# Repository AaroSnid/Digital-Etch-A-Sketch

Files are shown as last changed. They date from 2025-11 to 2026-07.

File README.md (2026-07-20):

# Digital Etch-A-Sketch

The **Digital Etch-A-Sketch** is a portable recreation of the classic Etch-A-Sketch drawing toy, built around an STM32 microcontroller, a 3.5" TFT display, and  rotary encoders for drawing cursor control. This project's main features are the rotary encoder cursor control, realistic screen erase gesture, and selectable drawing thickness.

> **Status:** Major Firmware Version Finalized
> **Hardware Version:** Rev1

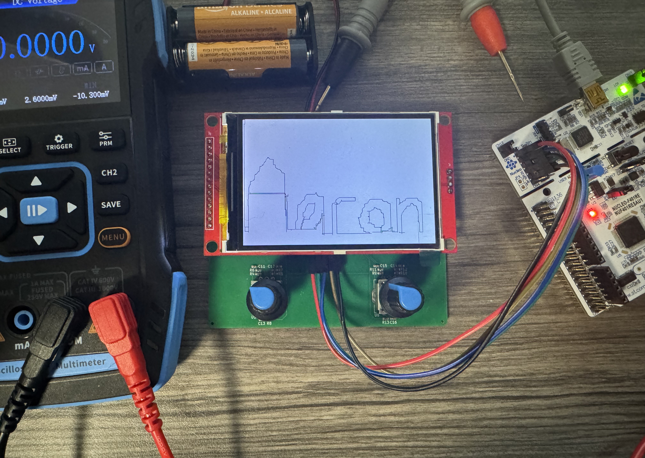
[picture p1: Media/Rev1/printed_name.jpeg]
PCB Rev1 with screen attached


---

## Features

- **Freehand Drawing**
  - Pixel-accurate cursor control
  - Trailless travel / eraser function
  - Selectable drawing thickness and brightness control

- **Physical Controls**
  - Two rotary encoders for X/Y movement
  - Encoder pushbuttons to for system setting selection

- **Shake to Erase**
  - Accelerometer detect motion for realistic screen erase gesture 

- **Portable & Low Power**
  - Powered by 2× AA batteries or by USB-C port

---

## Bill of Materials (Summary)

| Item | Part Number | Qty | Notes |
|---|---|-----|---|
| MCU | STM32L433CCT6 | 1 | Main controller |
| Display | 3.5" ILI9488 SPI | 1 | 3.5" display |
| QSPI Flash | For future expansion | 1 | Reserved for future use |
| 3-axis Accelerometer | LIS3DTHR | 1 | 3-axis velocity sensor |
| Rotary Encoder  | PEC11R-4215F-S0024 | 2 | User input |
| Battery Holder  | Adafruit 4194 | 1 | 2× AA |

---

## Hardware Subsystems

### Power Supply

- **Part:** Adafruit 4194
- **Input:** 2 × AA batteries (2.2–3.2 V)
- **Output:** 3.0 V 
- **Max Load:** ~400 mA
- **Purpose:** Powers the entire system from AA cells

---

### Microcontroller

- **Part:** STM32L433CCT3 / STM32L433CCT6  
- **Clock:** 80 MHz (internal)
- **Memory:**  
  - 256 KB Flash  
  - 64 KB RAM  

**Key Peripherals**

| Function | Peripheral | Notes |
|---|---|---|
| Display | SPI3 | Half-duplex, optimized for fast updates |
| Accelerometer | SPI2, EXTI | Full-duplex |
| Flash memory | Quad-SPI | Memory-mapped reads |
| Rotary Encoders  | TIM1&2, EXTI | QEI mode with interrupts |
| Debug | SWD | DIO, CLK, NRST |

---

### Display

- **Type:** 3.5" TFT Display
- **Controller:** ILI9488
- **Interface:** Dedicated 4-wire SPI
- **Power:** 3.3 V
- **Frame Buffer:** Embedded GRAM
- **Update Modes:** Full and partial refresh
The screen is mounted to the board using the female pin headers on either side. The touchscreen functionality of the screen is not used, so the touchscreen pins are not conected.

---

### Storage

- **Part:** For future expansion
- **Capacity:** Reserved for future use
- **Interface:** Quad SPI (if added later)
- **Purpose:**
  - Potential animation frame storage
  - Potential configuration data

---

### Motion Sensor

- **Part:** LIS3DTHR
- **Interface:** SPI
- **Capabilities:** 3-axis accelerometer
- **Usage:**
  - Detect shake gesture for screen erase
  - Uses interrupts for main motion detection
  - SPI available as fallback

---

### Rotary Encoders

- **Quantity:** 2
- **Part:** PEC11R-4215F-S0024
- **Purpose:**
  - X-axis and Y-axis cursor movement
  - UI interaction via push buttons

**Connections**
- A/B channels → Timer QEI inputs
- Buttons → EXTI interrupts
- Hardware Pull-ups (open-drain behavior)

---

## Firmware Architecture

### Overview

The firmware runs inside of a state machine, easily allowing for the same user inputs to be used for different purposes.
The main loop runs (per iteration) a check for the screen erase, handles state change, and then enters the state machine section for currently selected action.
An external driver is used for the ILI9488 display, all other firmware is made by me.

---

## Debug & Firmware Update

- **Interface:** SWD
- **Exposed Pins:**  
  - SWDIO  
  - SWCLK  
  - NRST  
  - VCC + GND

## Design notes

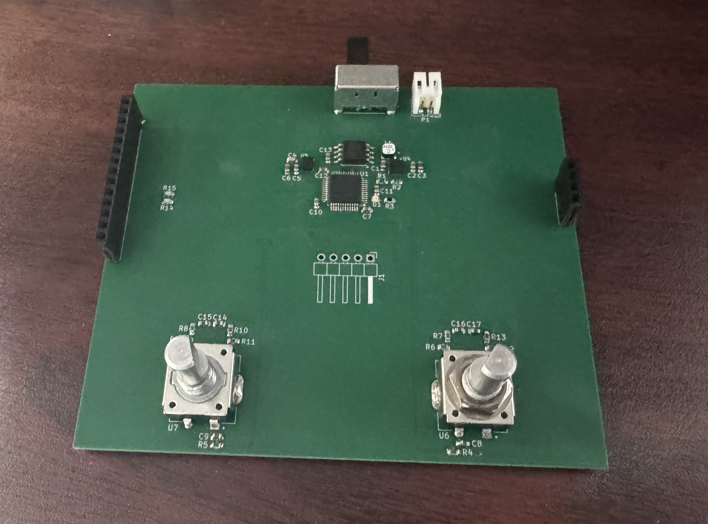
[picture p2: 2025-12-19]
Media/pcb_rev0.JPG

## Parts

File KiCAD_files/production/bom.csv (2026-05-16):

Designator | Footprint | Quantity | Value | LCSC Part #
C1, C10, C2, C20, C4, C5, C6 | 0603 | 7 | 0.1uF
C11, C12, C14, C15 | 0603 | 4 | 0.22uF
C13, C16 | 0603 | 2 | 0.47uF
C17, C18, C8 | 0603 | 3 | 1uF
C19, C3 | 0603 | 2 | 10uF
C7 | 0603 | 1 | 10nF
C9 | 0603 | 1 | 4.7uF
J1 | PinHeader_1x05_P2.54mm_Vertical | 1 | Debug Connector
J2 | PinSocket_1x14_P2.54mm_Vertical | 1 | Display / Mounting Socket
J3 | PinSocket_1x04_P2.54mm_Vertical | 1 | Display Mounting Socket
J4 | 2171790001_MOL | 1 | Molex 2171790001
P1 | JST_PH_B2B-PH-K_1x02_P2.00mm_Vertical | 1 | 282837-2
R1, R10, R11, R12, R13, R2, R3, R4, R5, R6, R7, R8, R9 | 0603 | 13 | 10K
R14, R15 | 0603 | 2 | 5.1kΩ
S1 | OS102011MA1QN1_CNK | 1 | OS102011MA1QN1
U1 | LQFP-48_7x7mm_P0.5mm | 1 | STM32L433CCTx
U2 | SOIC-8_5P28X5P28_WIN | 1 | W25Q64JV
U3 | LGA-16_3x3x1mm_STM | 1 | LIS3DHTR
U4 | SOT-23 | 1 | MCP1700x-300xxTT
U5, U6 | XDCR_PEC11R-4215F-S0024 | 2 | PEC11R_4215F_S0024

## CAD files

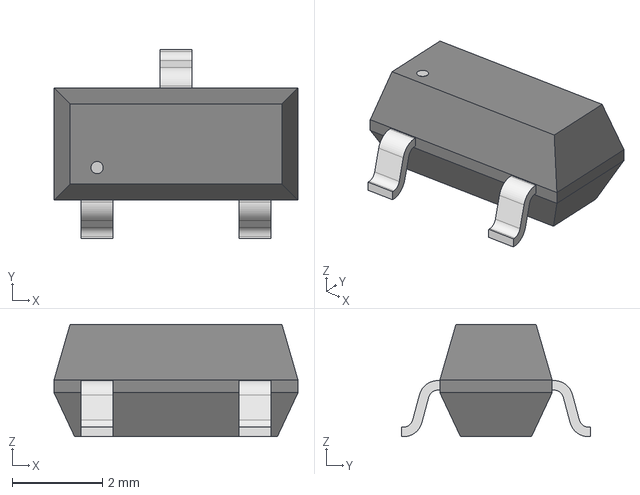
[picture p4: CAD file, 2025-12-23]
KiCAD_files/CJS_1200TB/CJS-1200B_NDC.step
5.41 x 4.19 x 2.49 mm

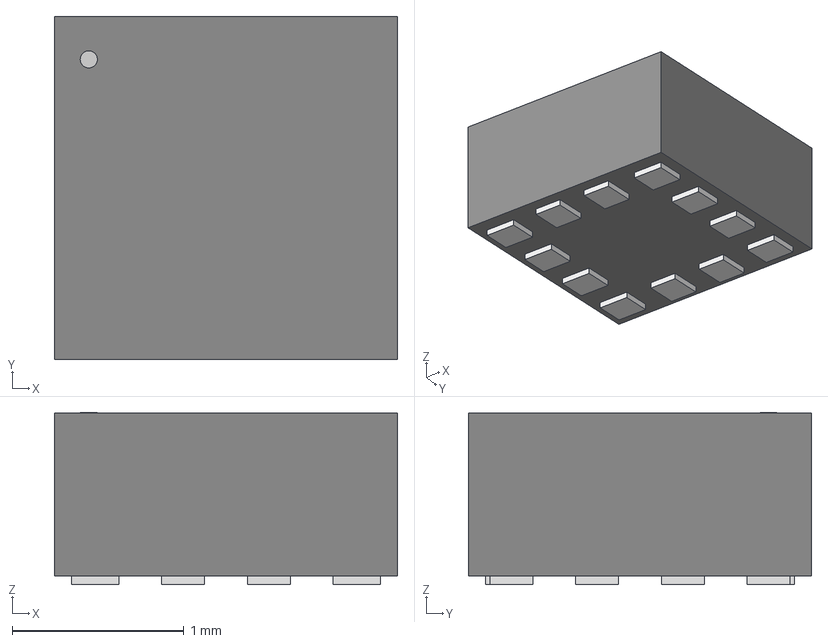
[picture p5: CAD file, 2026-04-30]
KiCAD_files/LIS2DH12TR/LGA-12_STM.step
2.00 x 2.00 x 1.00 mm

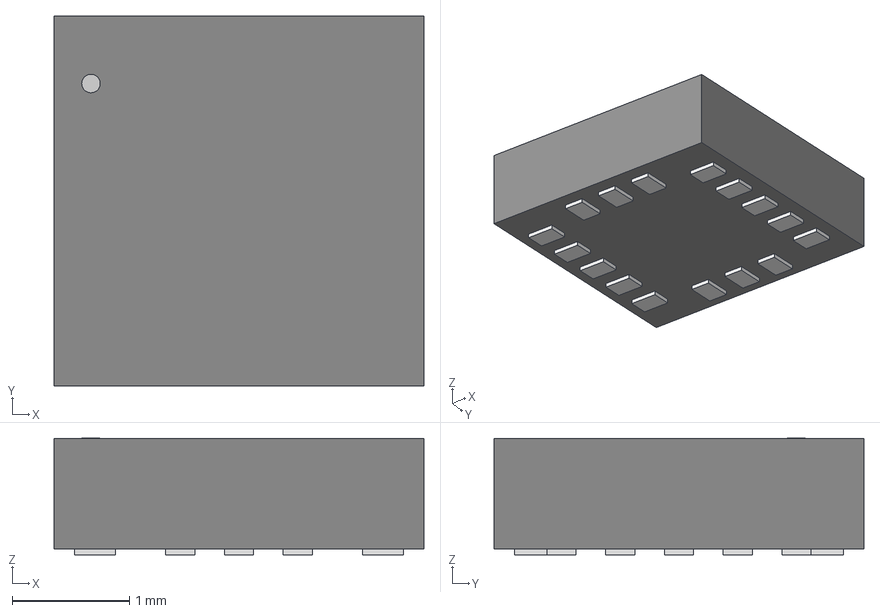
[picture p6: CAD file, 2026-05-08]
KiCAD_files/LIS3DHTR/LGA-16_3x3x1mm_STM.step
3.15 x 3.15 x 0.993 mm

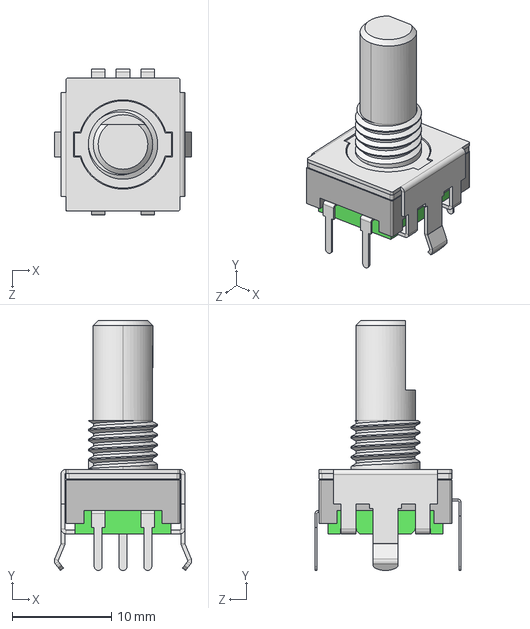
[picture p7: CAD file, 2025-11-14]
KiCAD_files/PEC11R_4215F_S0024/PEC11R-4215F-S0024.step
13.9 x 25.2 x 14.7 mm

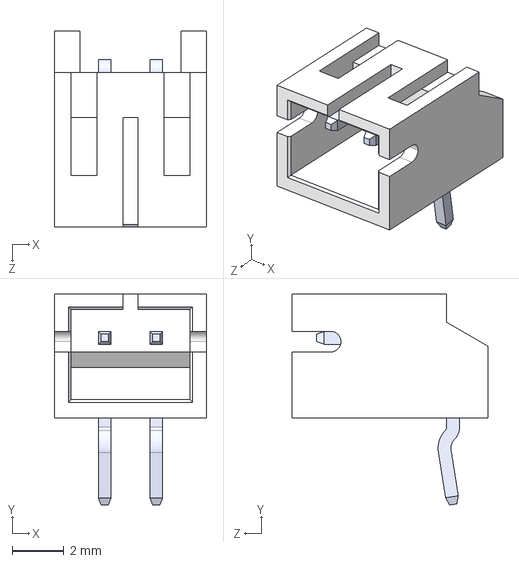
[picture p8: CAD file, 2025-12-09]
KiCAD_files/S2B_PH_K_S/S2B-PH-K-S.STEP
5.90 x 8.18 x 7.60 mm

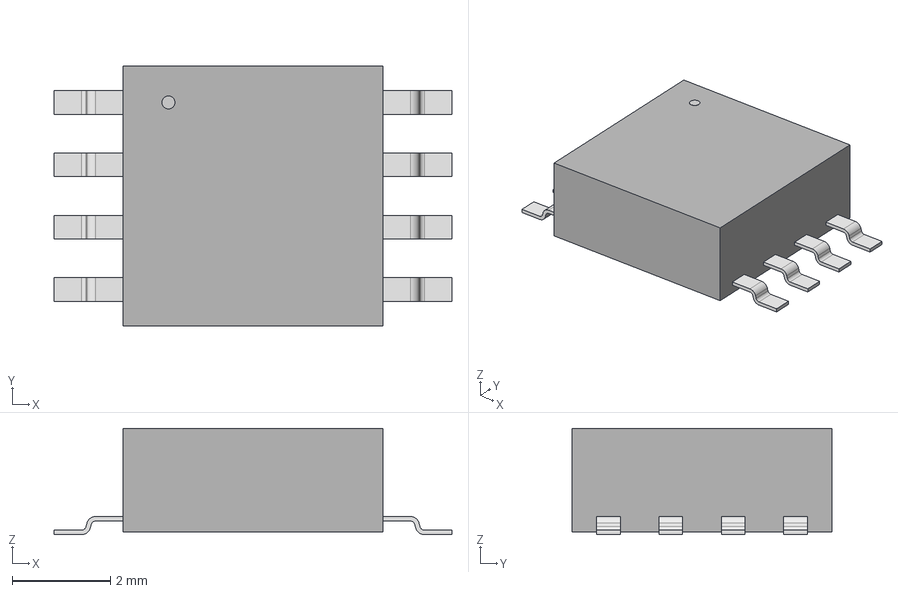
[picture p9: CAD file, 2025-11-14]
KiCAD_files/W25Q64JVSSIQ/SOIC-8_5P28X5P28_WIN.step
8.10 x 5.28 x 2.16 mm

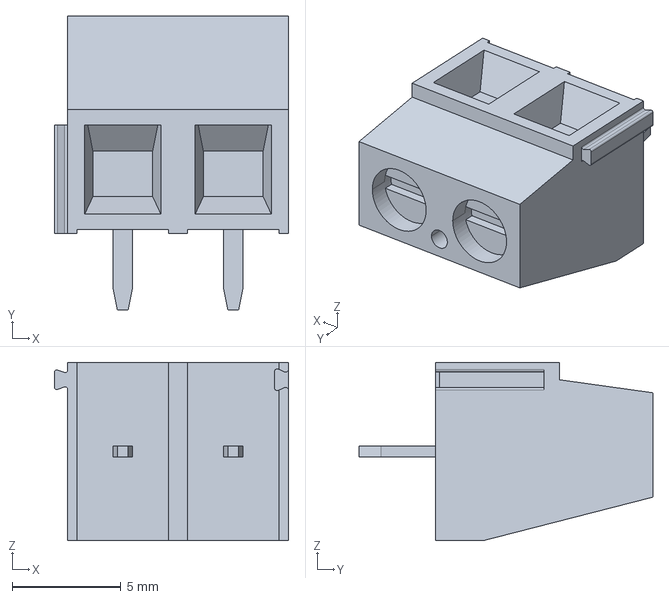
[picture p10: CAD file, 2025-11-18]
KiCAD_files/282837_2/282837-2.step
10.8 x 13.5 x 8.20 mm

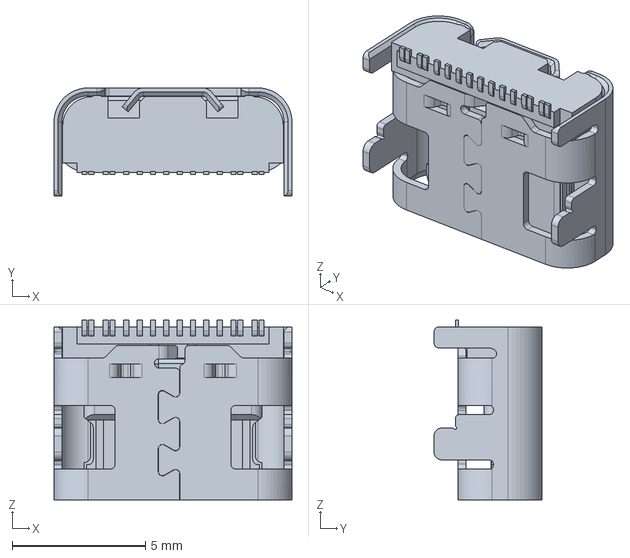
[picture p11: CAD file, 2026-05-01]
KiCAD_files/Molex2171790001/2171790001.stp
8.94 x 4.06 x 6.75 mm

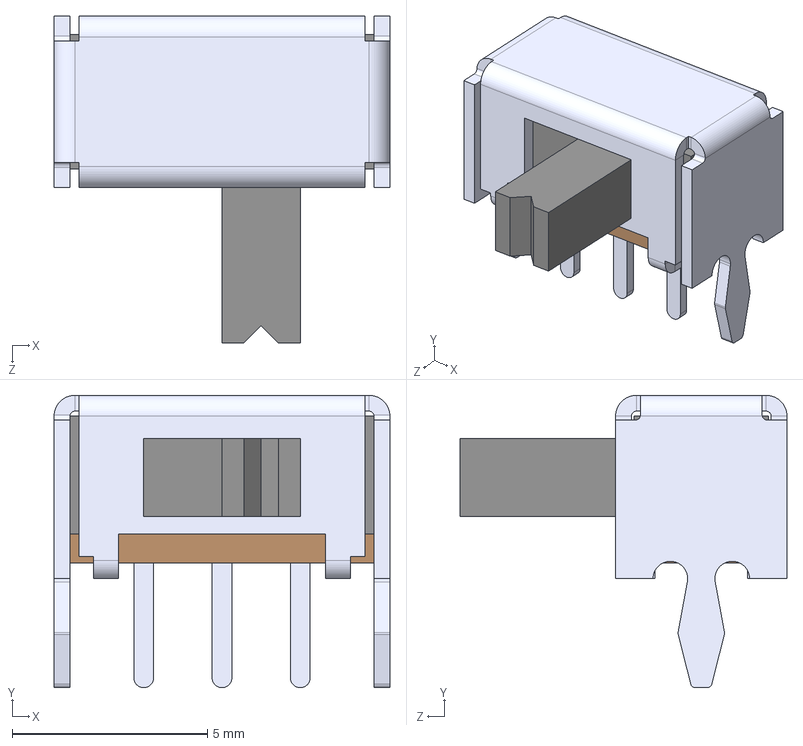
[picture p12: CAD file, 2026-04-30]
KiCAD_files/OS102011MA1QN1/OS102011MA1QN1.STEP
8.61 x 7.49 x 8.38 mm

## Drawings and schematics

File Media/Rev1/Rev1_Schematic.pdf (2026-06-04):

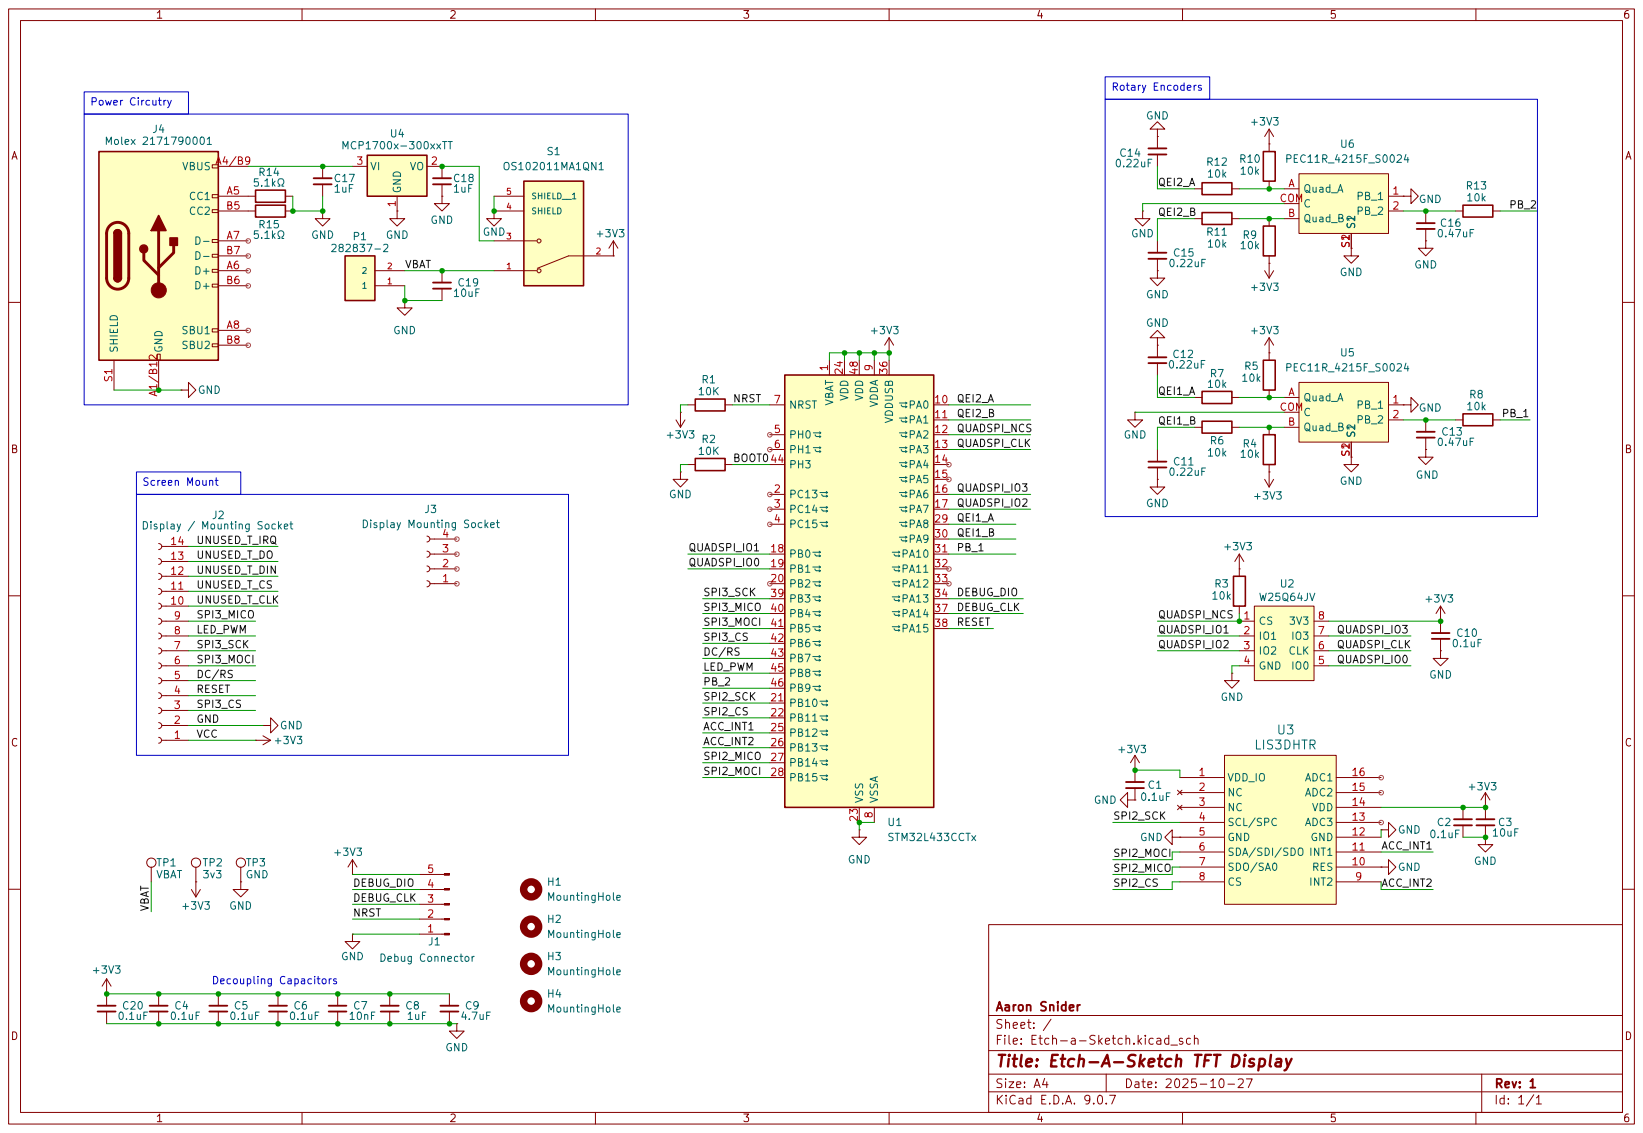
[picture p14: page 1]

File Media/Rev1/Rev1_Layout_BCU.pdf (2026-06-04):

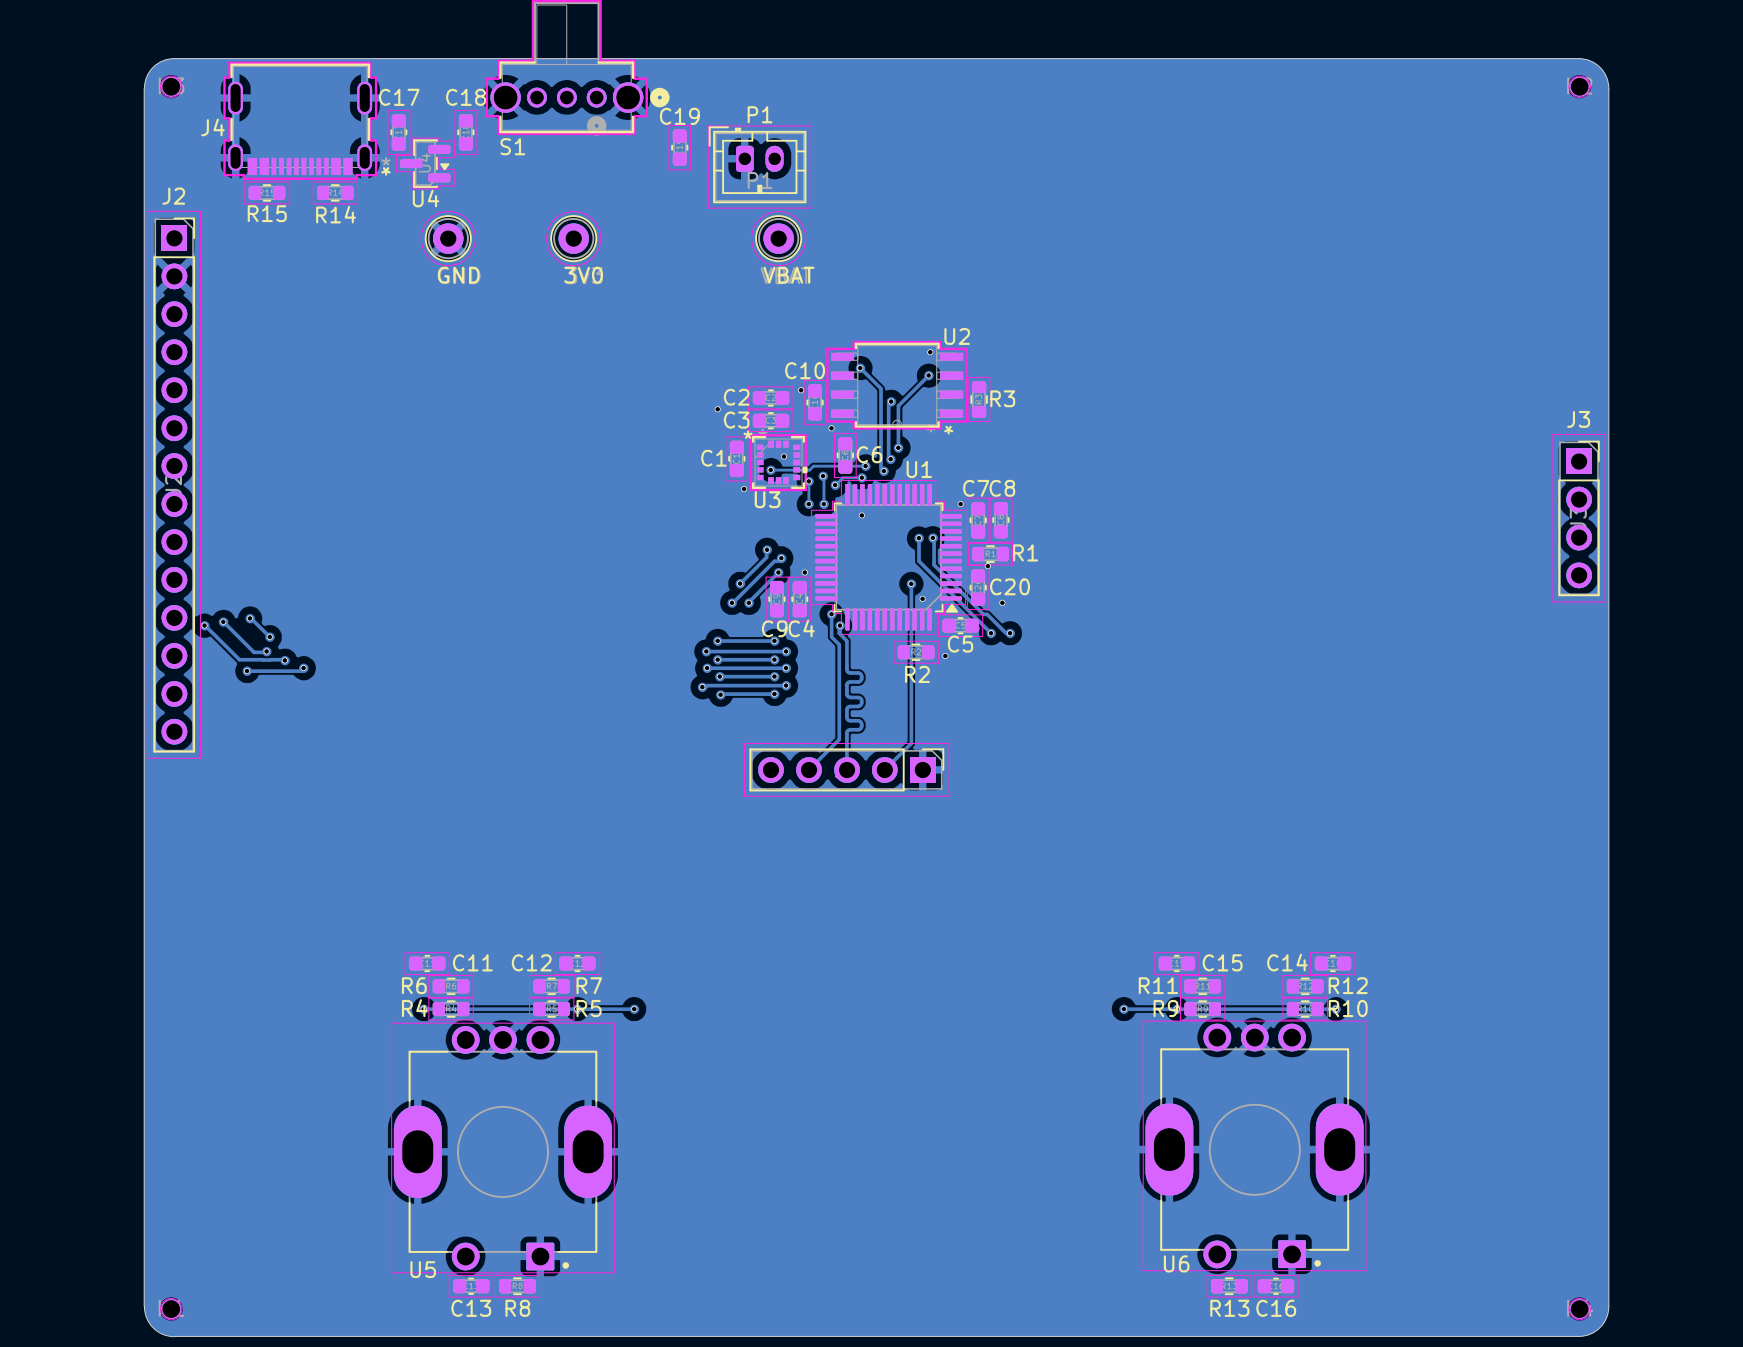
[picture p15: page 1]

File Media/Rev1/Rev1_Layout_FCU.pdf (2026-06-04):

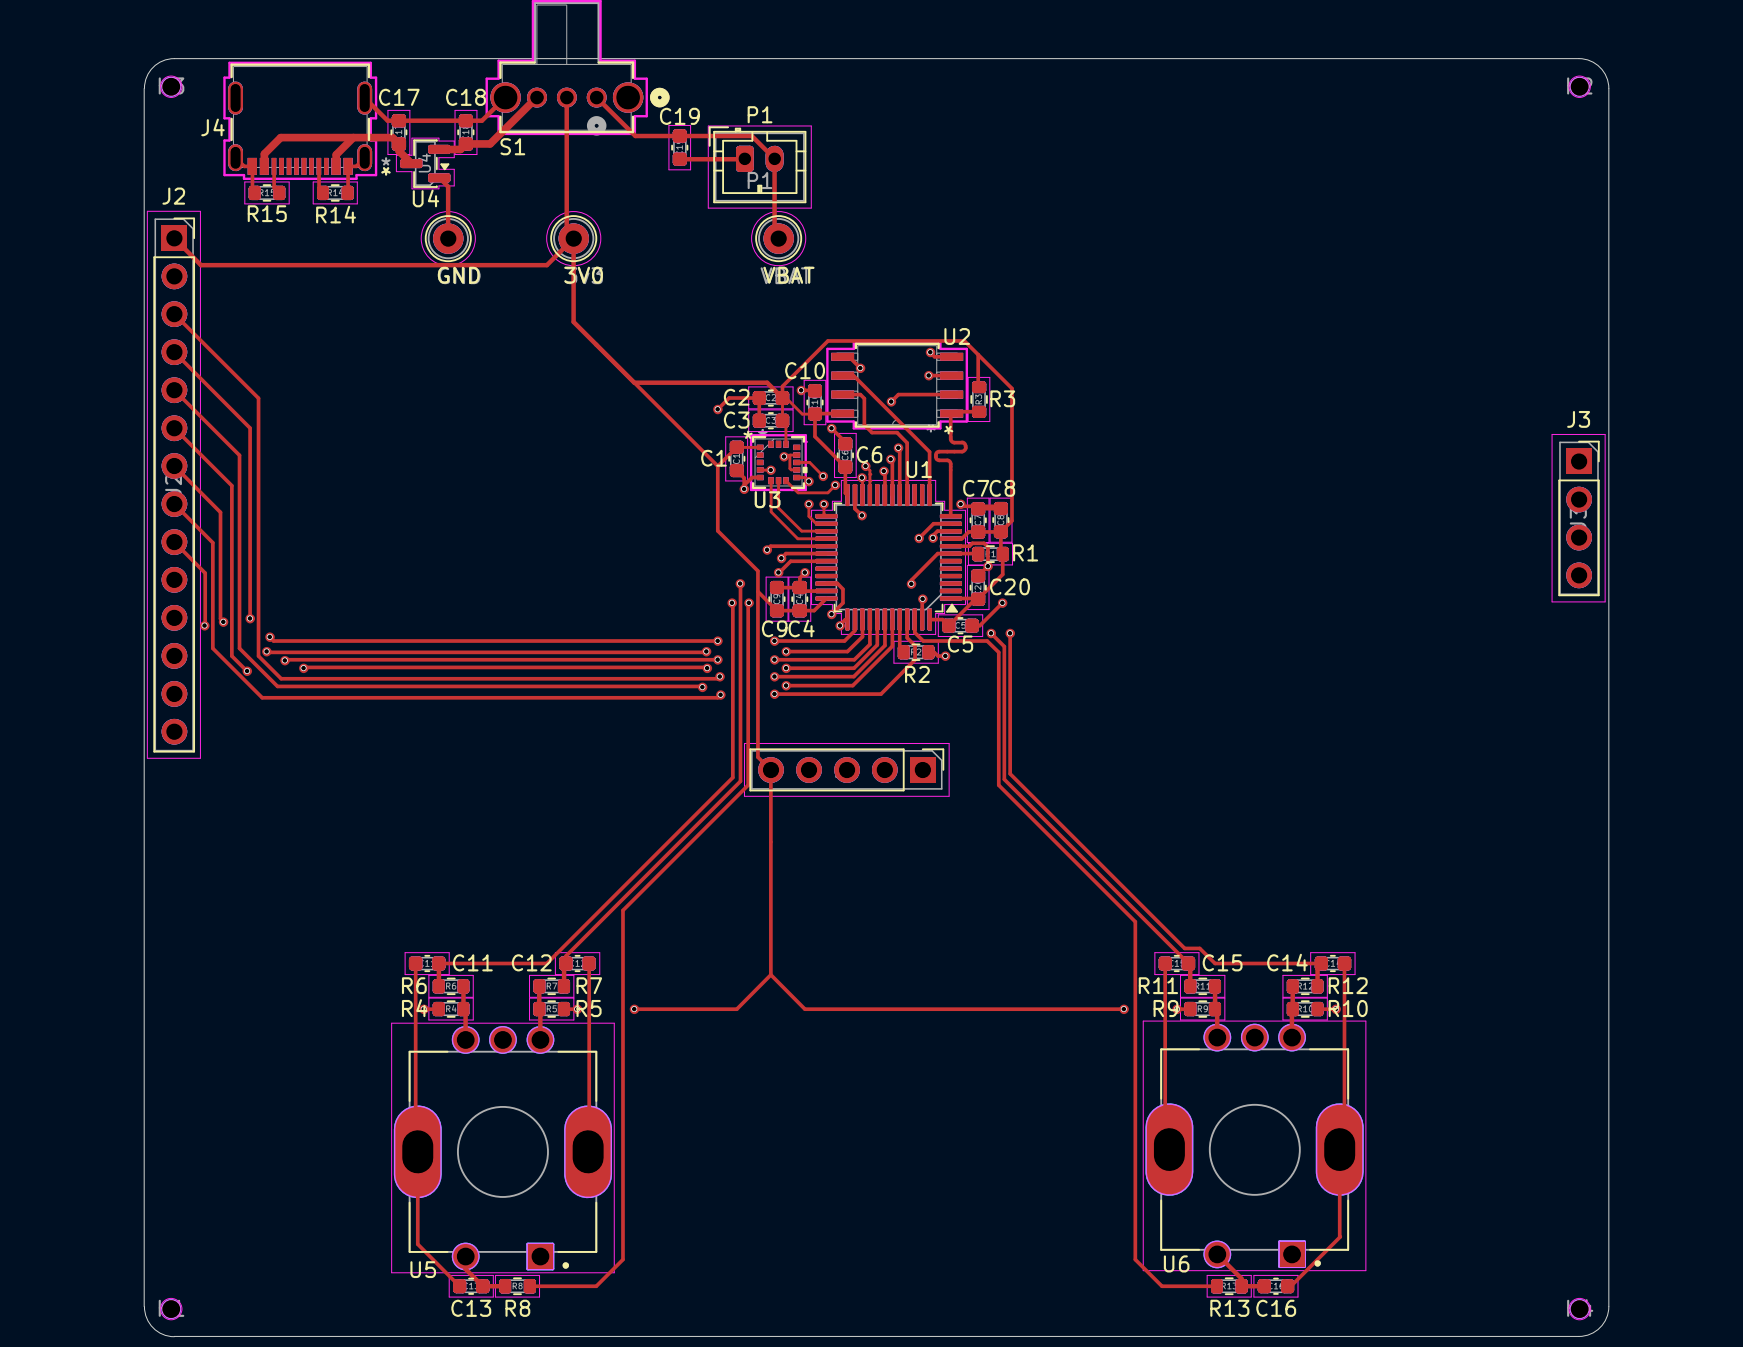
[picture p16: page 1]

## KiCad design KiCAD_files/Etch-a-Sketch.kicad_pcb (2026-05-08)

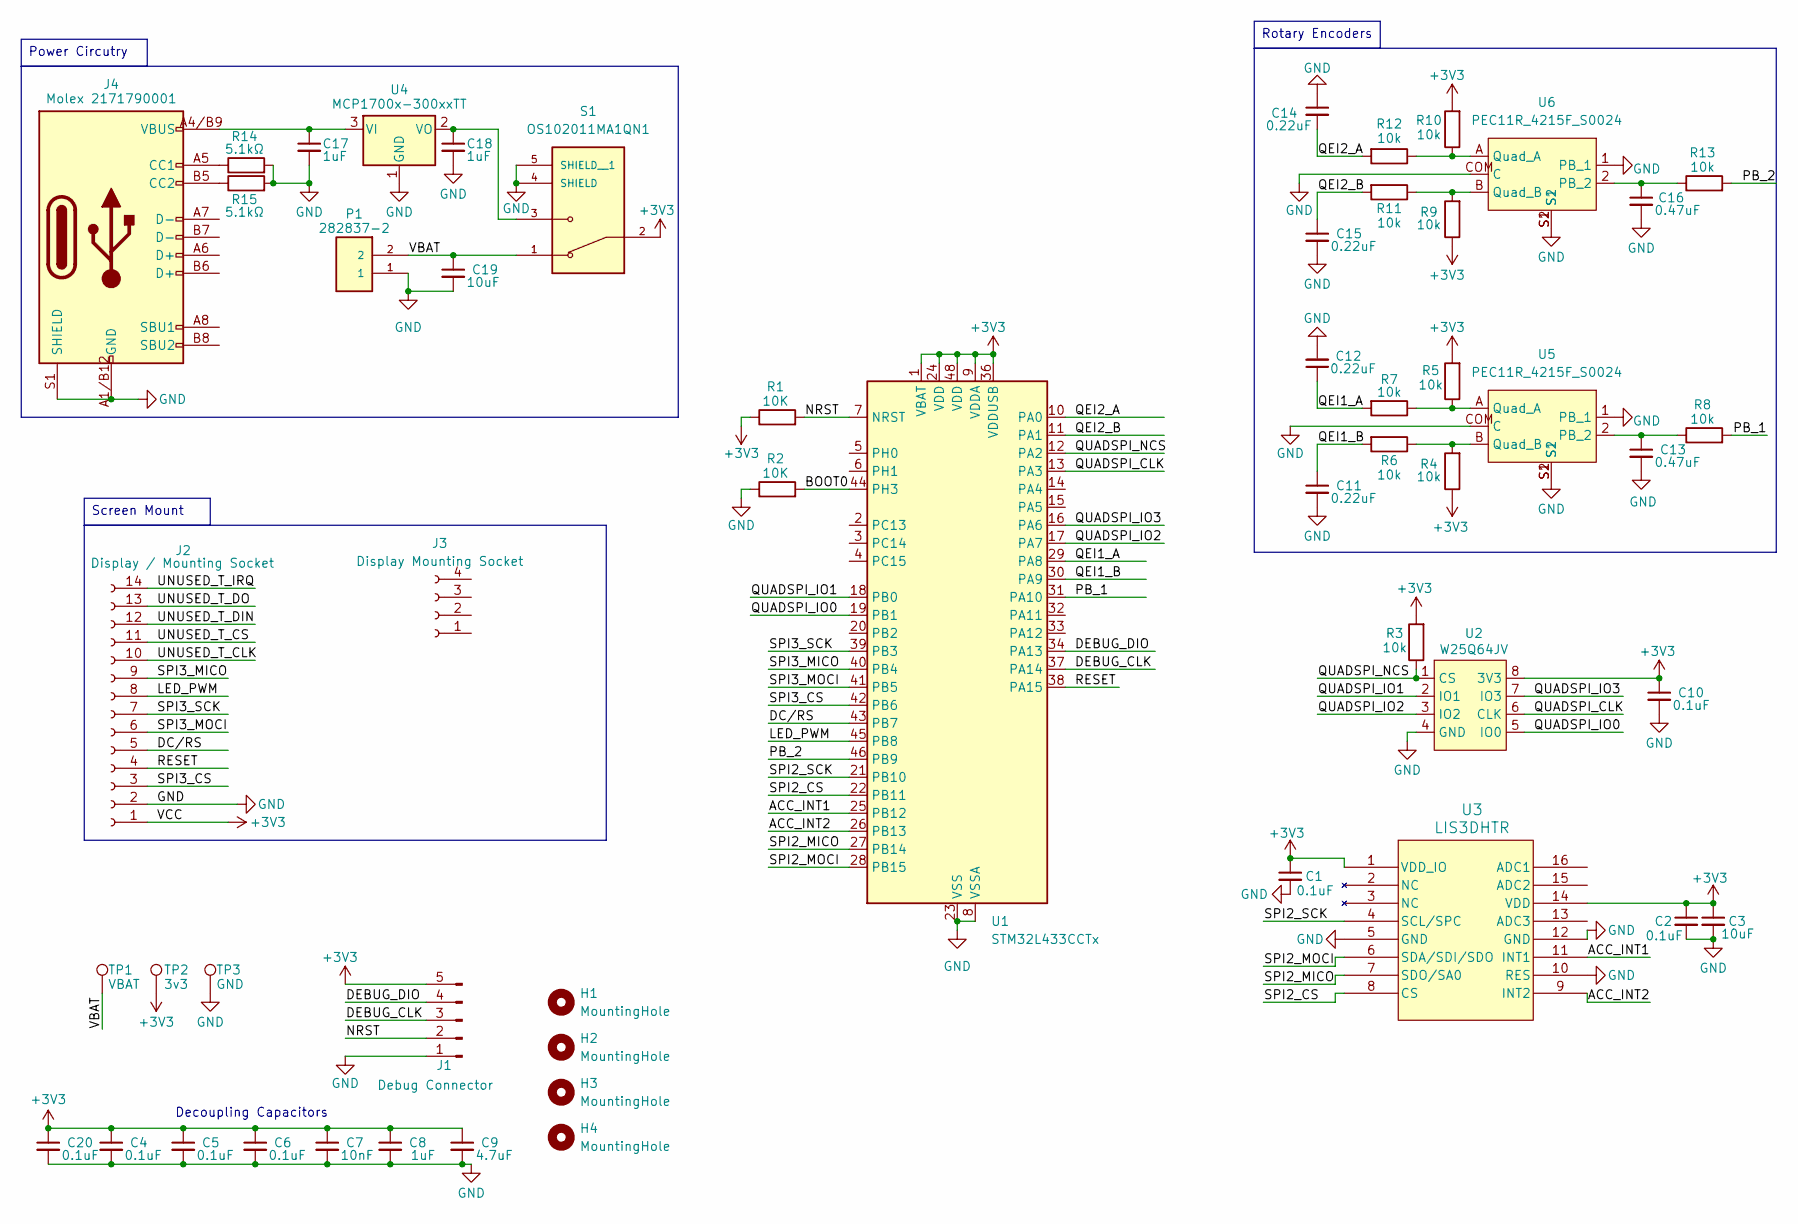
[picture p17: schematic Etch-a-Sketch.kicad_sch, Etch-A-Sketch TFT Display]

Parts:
C1, C2, C4, C5, C6, C10, C20: 0.1uF; C_0603_1608Metric
C3, C19: 10uF; C_0603_1608Metric
C7: 10nF; C_0603_1608Metric
C8, C17, C18: 1uF; C_0603_1608Metric
C9: 4.7uF; C_0603_1608Metric
C11, C12, C14, C15: 0.22uF; C_0603_1608Metric
C13, C16: 0.47uF; C_0603_1608Metric
H1, H2, H3, H4: MountingHole; ToolingHole_1.152mm
J1: Debug Connector; PinHeader_1x05_P2.54mm_Vertical
J2: Display / Mounting Socket; PinSocket_1x14_P2.54mm_Vertical
J3: Display Mounting Socket; PinSocket_1x04_P2.54mm_Vertical
J4: Molex 2171790001; 2171790001_MOL
P1: 282837-2; JST_PH_B2B-PH-K_1x02_P2.00mm_Vertical; PARTREV G3
R1, R2: 10K; R_0603_1608Metric
R3, R4, R5, R6, R7, R8, R9, R10, R11, R12, R13: 10k; R_0603_1608Metric
R14, R15: 5.1kΩ; R_0603_1608Metric
S1: OS102011MA1QN1; OS102011MA1QN1_CNK; PARTREV A
TP1: VBAT; TestPoint_Loop_D1.80mm_Drill1.0mm_Beaded
TP2: 3v3; TestPoint_Loop_D1.80mm_Drill1.0mm_Beaded
TP3: GND; TestPoint_Loop_D1.80mm_Drill1.0mm_Beaded
U1: STM32L433CCTx; LQFP-48_7x7mm_P0.5mm
U2: W25Q64JV; SOIC-8_5P28X5P28_WIN
U3: LIS3DHTR; LGA-16_3x3x1mm_STM
U4: MCP1700x-300xxTT; SOT-23
U5, U6: PEC11R_4215F_S0024; XDCR_PEC11R-4215F-S0024

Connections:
+3V3: C1.1, C2.1, C3.1, C4.1, C5.1, C6.1, C7.1, C8.1, C9.1, C10.1, C20.1, J1.5, J2.1, R1.1, R3.2, R4.1, R5.2, R9.1, R10.2, S1.2, TP2.1, U1.1 (VBAT), U1.9 (VDDA), U1.24 (VDD), U1.36 (VDDUSB), U1.48 (VDD), U2.8 (3V3), U3.1 (VDD_IO), U3.14 (VDD); also elsewhere on the board
/ACC_INT1: U1.25 (PB12), U3.11 (INT1)
/ACC_INT2: U1.26 (PB13), U3.9 (INT2)
/BOOT0: R2.2, U1.44 (PH3)
/DC/RS: J2.5, U1.43 (PB7)
/DEBUG_CLK: J1.3, U1.37 (PA14)
/DEBUG_DIO: J1.4, U1.34 (PA13)
/LED_PWM: J2.8, U1.45 (PB8)
/NRST: J1.2, R1.2, U1.7 (NRST)
/PB_1: R8.2, U1.31 (PA10)
/PB_2: R13.2, U1.46 (PB9)
/QEI1_A: C12.1, R7.2, U1.29 (PA8)
/QEI1_B: C11.1, R6.2, U1.30 (PA9)
/QEI2_A: C14.2, R12.2, U1.10 (PA0)
/QEI2_B: C15.1, R11.2, U1.11 (PA1)
/QUADSPI_CLK: U1.13 (PA3), U2.6 (CLK)
/QUADSPI_IO0: U1.19 (PB1), U2.5 (IO0)
/QUADSPI_IO1: U1.18 (PB0), U2.2 (IO1)
/QUADSPI_IO2: U1.17 (PA7), U2.3 (IO2)
/QUADSPI_IO3: U1.16 (PA6), U2.7 (IO3)
/QUADSPI_NCS: R3.1, U1.12 (PA2), U2.1 (CS)
/RESET: J2.4, U1.38 (PA15)
/SPI2_CS: U1.22 (PB11), U3.8 (CS)
/SPI2_MICO: U1.27 (PB14), U3.7 (SDO/SA0)
/SPI2_MOCI: U1.28 (PB15), U3.6 (SDA/SDI/SDO)
/SPI2_SCK: U1.21 (PB10), U3.4 (SCL/SPC)
/SPI3_CS: J2.3, U1.42 (PB6)
/SPI3_MICO: J2.9, U1.40 (PB4)
/SPI3_MOCI: J2.6, U1.41 (PB5)
/SPI3_SCK: J2.7, U1.39 (PB3)
/UNUSED_T_CLK: J2.10
/UNUSED_T_CS: J2.11
/UNUSED_T_DIN: J2.12
/UNUSED_T_DO: J2.13
/UNUSED_T_IRQ: J2.14
/VBAT: C19.1, P1.2, S1.1, TP1.1; also elsewhere on the board
GND: C1.2, C2.2, C3.2, C4.2, C5.2, C6.2, C7.2, C8.2, C9.2, C10.2, C11.2, C12.2, C13.2, C14.1, C15.2, C16.2, C17.2, C18.2, C19.2, C20.2, J1.1, J2.2, J4.A1/B12 (GND), J4.B1/A12 (GND), J4.S1 (SHIELD), P1.1, R2.1, R14.2, R15.2, S1.4 (SHIELD), S1.5 (SHIELD__1), TP3.1, U1.8 (VSSA), U1.23 (VSS), U1.35 (VSS), U1.47 (VSS), U2.4 (GND), U3.5 (GND), U3.10 (RES), U3.12 (GND), U4.1 (GND), U5.1 (PB_1), U5.COM (C), U5.S1, U5.S2, U6.1 (PB_1), U6.COM (C), U6.S1, U6.S2; also elsewhere on the board
unnamed: J4.A5 (CC1), R14.1
unnamed: J4.B5 (CC2), R15.1
unnamed: C17.1, J4.A4/B9 (VBUS), J4.B4/A9 (VBUS), U4.3 (VI)
unnamed: C18.1, S1.3, U4.2 (VO)
unnamed: C13.1, R8.1, U5.2 (PB_2)
unnamed: R5.1, R7.1, U5.A (Quad_A)
unnamed: R4.2, R6.1, U5.B (Quad_B)
unnamed: C16.1, R13.1, U6.2 (PB_2)
unnamed: R10.1, R12.1, U6.A (Quad_A)
unnamed: R9.2, R11.1, U6.B (Quad_B)

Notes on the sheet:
Decoupling Capacitors
Screen Mount
Rotary Encoders
Power Circutry

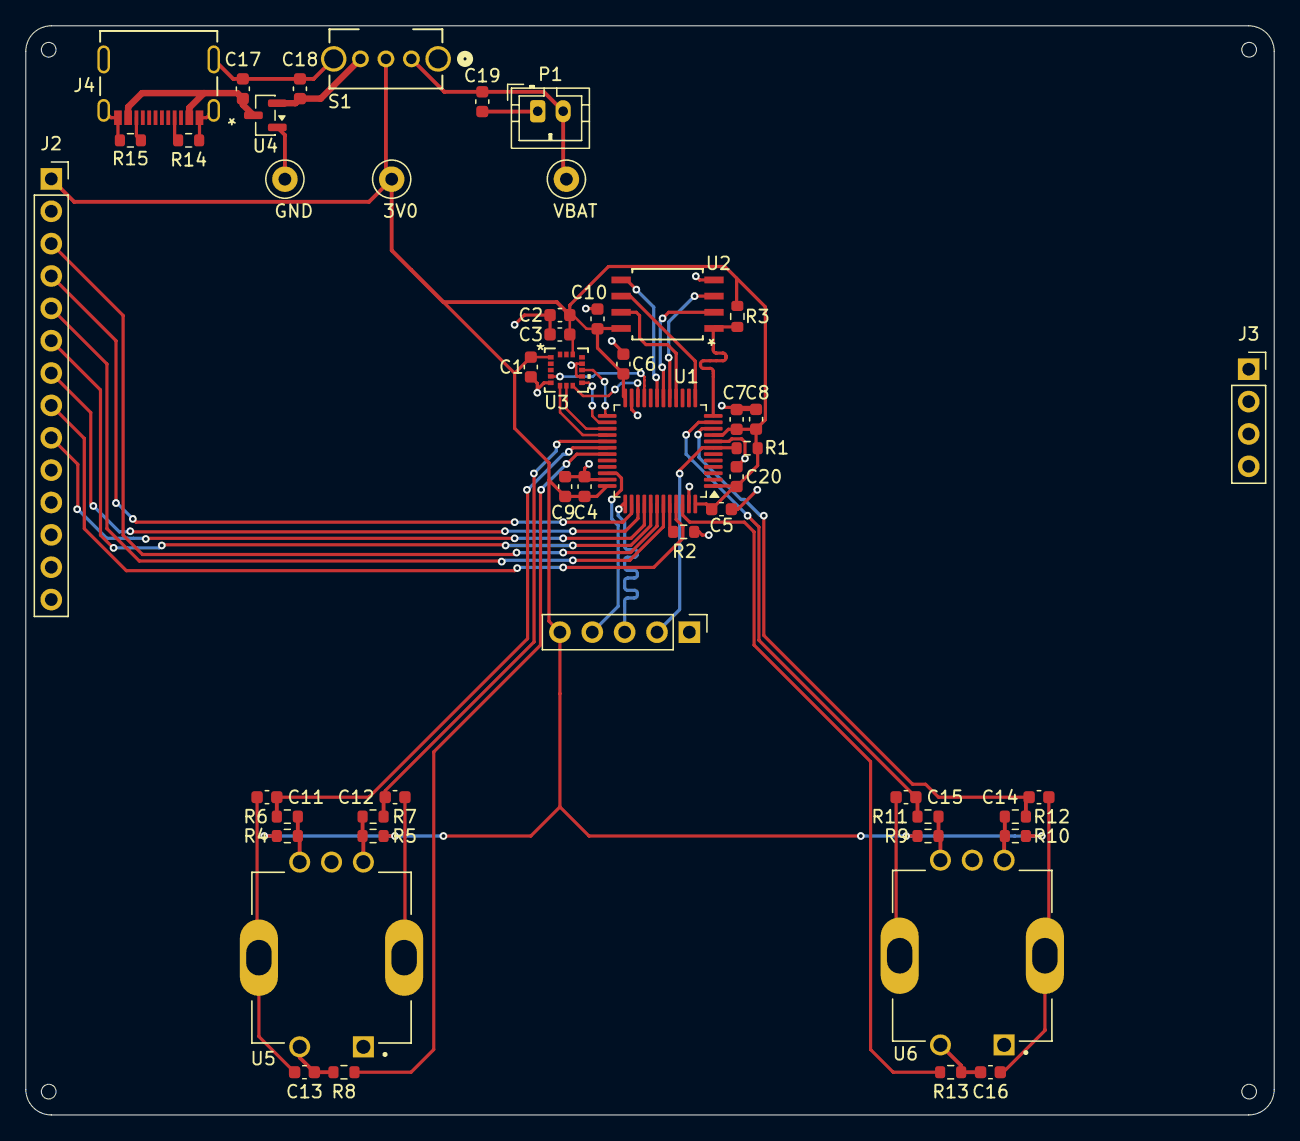
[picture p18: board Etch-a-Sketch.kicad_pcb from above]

Board: 2 copper layers, 98.0 x 85.5 mm, 54 parts (0 on the bottom side), 42 nets.

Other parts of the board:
3V0: 3v3; TestPoint_Loop_D1.80mm_Drill1.0mm_Beaded
GND: GND; TestPoint_Loop_D1.80mm_Drill1.0mm_Beaded
VBAT: VBAT; TestPoint_Loop_D1.80mm_Drill1.0mm_Beaded

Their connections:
+3V3: 3V0.1; also elsewhere on the board
/VBAT: VBAT.1; also elsewhere on the board
GND: GND.1; also elsewhere on the board

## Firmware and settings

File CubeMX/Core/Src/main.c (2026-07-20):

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
/* Includes ------------------------------------------------------------------*/
#include "main.h"

/* USER CODE BEGIN Includes */

#include "ili9488.h"
#include "lis3dhtr.h"
#include <stdint.h>

/* USER CODE END Includes */

/* USER CODE BEGIN PTD */

typedef enum {
  SYSTEM_STATE_DRAWING,
  SYSTEM_STATE_ERASING,
  SYSTEM_STATE_DIMMING,
  SYSTEM_STATE_THICKNESS_SELECT,
} system_states;

/* USER CODE END PTD */

/* USER CODE BEGIN PD */

#define ETCH_A_SKETCH_GREY 0xD592

#define MAX_CURSOR_THICKNESS 40   // Capped for visual and performance reasons

// Use classic grey background
#if 0
#define BACKGROUND_COLOR ETCH_A_SKETCH_GREY
#else
#define BACKGROUND_COLOR 0xFFFF
#endif

/* USER CODE END PD */

QSPI_HandleTypeDef hqspi;

SPI_HandleTypeDef hspi2;
SPI_HandleTypeDef hspi3;

TIM_HandleTypeDef htim1;
TIM_HandleTypeDef htim2;
TIM_HandleTypeDef htim16;

/* USER CODE BEGIN PV */

system_states state = SYSTEM_STATE_DRAWING;

lis3dhtr_cfg_t lis3dhtr_cfg;

volatile bool shake_event_flag = 0;
volatile bool confirm_clear_screen_flag = 0;

uint16_t last_x_pos = 1;
uint16_t last_y_pos = 1;
uint16_t previous_selector_cnt = 0;

uint8_t system_line_thickness = 1;
uint8_t previous_system_line_thickness = 1;

volatile bool pb1_interrupt_fired = false;
volatile bool pb2_interrupt_fired = false;


/* USER CODE END PV */

void SystemClock_Config(void);
static void MX_GPIO_Init(void);
static void MX_QUADSPI_Init(void);
static void MX_SPI2_Init(void);
static void MX_SPI3_Init(void);
static void MX_TIM1_Init(void);
static void MX_TIM2_Init(void);
static void MX_TIM16_Init(void);
/* USER CODE BEGIN PFP */

static void clear_screen(int colour);
static void fill_cursor_box(uint16_t x, uint16_t y, uint8_t thickness, uint16_t colour);

/* USER CODE END PFP */

/**
  * @brief  The application entry point.
  * @retval int
  */
int main(void)
{

  /* MCU Configuration--------------------------------------------------------*/

  /* Reset of all peripherals, Initializes the Flash interface and the Systick. */
  HAL_Init();

  /* Configure the system clock */
  SystemClock_Config();

  /* Initialize all configured peripherals */
  MX_GPIO_Init();
  MX_QUADSPI_Init();
  MX_SPI2_Init();
  MX_SPI3_Init();
  MX_TIM1_Init();
  MX_TIM2_Init();
  MX_TIM16_Init();
  /* USER CODE BEGIN 2 */

  // Set initial PWM to max duty cycle for full brightness
  TIM16->CCR1 = TIM16->ARR; 
  HAL_TIM_PWM_Start(&htim16, TIM_CHANNEL_1);

  // Start rotary encoder inputs
  HAL_TIM_Encoder_Start(&htim2, TIM_CHANNEL_ALL);
  HAL_TIM_Encoder_Start(&htim1, TIM_CHANNEL_ALL);

  // Configure LCD screen registers
  ILI9488_Init();
  setRotation(3);                             // Set landscape mode. 0, 0 in bottom right
  clear_screen(BACKGROUND_COLOR);    // Set screen to blank colour 
  
  lis3dh_init(&lis3dhtr_cfg, &hspi2, SPI2_CS_GPIO_Port, SPI2_CS_Pin);
  lis3dh_configure_data(&lis3dhtr_cfg, LIS3DH_ODR_100HZ, LIS3DH_2, LIS3DH_MODE_NORMAL, 0x07);
  lis3dh_configure_shake_to_erase(&lis3dhtr_cfg, true);

  // Set default cursor position
  TIM1->CNT = 0;
  TIM2->CNT = 0;

  /* USER CODE END 2 */

  /* Infinite loop */
  /* USER CODE BEGIN WHILE */
  while (1)
  {

    if (shake_event_flag == true){

      // Check if device was facing down at time of interrupt
      if (confirm_clear_screen_flag == true){

        clear_screen(BACKGROUND_COLOR);
        confirm_clear_screen_flag = false;
      }

        // Clear interrupt latch from accelerometer
        uint8_t clear_token;
        lis3dh_read_interrupt_source(&lis3dhtr_cfg, LIS3DH_INT_PIN_1, &clear_token);

        shake_event_flag = false;
    }

    // Handle state change outside ISR
    if (pb1_interrupt_fired){
      switch (state) {
        case SYSTEM_STATE_DRAWING:
          // First PB1 press enters dimming mode
          last_x_pos = TIM1->CNT / 4;
          last_y_pos = TIM2->CNT / 4;
          TIM2->CNT = (TIM16->CCR1 * TIM2->ARR) / TIM16->ARR;
          previous_selector_cnt = TIM2->CNT;
          state = SYSTEM_STATE_DIMMING;
          break;

        case SYSTEM_STATE_DIMMING:
          // Second PB1 press enters thickness selection mode
          // last_x/y_pos already hold the original drawing position
          TIM2->CNT = (TIM2->ARR * system_line_thickness) / (MAX_CURSOR_THICKNESS);
          previous_selector_cnt = TIM2->CNT;
          state = SYSTEM_STATE_THICKNESS_SELECT;
          break;

        case SYSTEM_STATE_THICKNESS_SELECT:
          // Third PB1 press returns to normal drawing mode
          TIM1->CNT = last_x_pos * 4;
          TIM2->CNT = last_y_pos * 4;
          state = SYSTEM_STATE_DRAWING;

          // Prevent aritifact from previous state from showing
          fill_cursor_box(last_x_pos, last_y_pos, system_line_thickness, TFT9341_BLACK);
          break;

        default:
          state = SYSTEM_STATE_DRAWING;
          break;
      }
      pb1_interrupt_fired = false;
    }

    if (pb2_interrupt_fired){
        if (state == SYSTEM_STATE_ERASING) {
          state = SYSTEM_STATE_DRAWING;
          // Prevent aritifact from previous state from showing
          fill_cursor_box(last_x_pos, last_y_pos, system_line_thickness, TFT9341_BLACK);
        } else {
          // last_x_pos/last_y_pos already hold the real saved drawing position
          if (state == SYSTEM_STATE_DRAWING) {
            last_x_pos = TIM1->CNT / 4;
            last_y_pos = TIM2->CNT / 4;
          } else {
            // Coming from DIMMING/THICKNESS_SELECT
            TIM1->CNT = last_x_pos * 4;
            TIM2->CNT = last_y_pos * 4;
          }
          state = SYSTEM_STATE_ERASING;
          // Prevent aritifact from previous state from showing
          uint8_t box_thickness = (system_line_thickness > 2) ? (system_line_thickness - 2) : system_line_thickness;
          fill_cursor_box((last_x_pos + 1), (last_y_pos + 1), box_thickness, BACKGROUND_COLOR);
          
        }
        pb2_interrupt_fired = false;
    }

    // Enter code state machine
    switch (state){

      // Drawing cursor tracking encoders
      case (SYSTEM_STATE_DRAWING): {
        // Convert register values to cursor position
        uint16_t x_pos = TIM1->CNT / 4;
        uint16_t y_pos = TIM2->CNT / 4;

        if (x_pos != last_x_pos){
          uint16_t line_length = (x_pos > last_x_pos) ? (x_pos - last_x_pos) : (last_x_pos - x_pos);

          // Check for wrap overflow or underflow
          if (line_length > 440){
            // Normalize to border, recalculate length
            last_x_pos = (last_x_pos > 240) ? 0 : 480;
            line_length = (x_pos > last_x_pos) ? (x_pos - last_x_pos) : (last_x_pos - x_pos);
          }

          // Start point must be on the right
          uint16_t start_point = (x_pos > last_x_pos) ? last_x_pos : x_pos;

          // Draw a centered square the size square the cursor represents
          uint16_t half_thickness = system_line_thickness / 2;
          uint16_t square_x = (start_point >= half_thickness) ? (start_point - half_thickness) : 0;
          uint16_t square_y = (last_y_pos >= half_thickness) ? (last_y_pos - half_thickness) : 0;
          fillRect(square_x, square_y, line_length + system_line_thickness, system_line_thickness, TFT9341_BLACK);
          last_x_pos = x_pos;
        }

        if (y_pos != last_y_pos){
          uint16_t line_length = (y_pos > last_y_pos) ? (y_pos - last_y_pos) : (last_y_pos - y_pos);

          // Check for wrap overflow or underflow
          if (line_length > 300){
            // Normalize to border, recalculate line_length
            last_y_pos = (last_y_pos > 160) ? 0 : 320;
            line_length = (y_pos > last_y_pos) ? (y_pos - last_y_pos) : (last_y_pos - y_pos);
          }

          // Start point must be on the bottom
          uint16_t start_point = (y_pos > last_y_pos) ? last_y_pos : y_pos;

          // Draw a centered square the size square the cursor represents
          uint16_t half_thickness = system_line_thickness / 2;
          uint16_t square_x = (last_x_pos >= half_thickness) ? (last_x_pos - half_thickness) : 0;
          uint16_t square_y = (start_point >= half_thickness) ? (start_point - half_thickness) : 0;
          fillRect(square_x, square_y, system_line_thickness, line_length + system_line_thickness, TFT9341_BLACK);
          last_y_pos = y_pos;
        }
        break;
      }

      case (SYSTEM_STATE_ERASING): {
        // Convert register values to cursor position
        uint16_t erase_x_pos = TIM1->CNT / 4;
        uint16_t erase_y_pos = TIM2->CNT / 4;

        // Since it only regenerates on movement, there should be no flickering (no delay needed)
        if ((erase_x_pos != last_x_pos) || (erase_y_pos != last_y_pos)) {
          uint16_t half_thickness = system_line_thickness / 2;
          uint16_t old_square_x = (last_x_pos >= half_thickness) ? (last_x_pos - half_thickness) : 0;
          uint16_t old_square_y = (last_y_pos >= half_thickness) ? (last_y_pos - half_thickness) : 0;
          fillRect(old_square_x, old_square_y, system_line_thickness, system_line_thickness, BACKGROUND_COLOR);

          last_x_pos = erase_x_pos;
          last_y_pos = erase_y_pos;
          uint16_t new_square_x = (last_x_pos >= half_thickness) ? (last_x_pos - half_thickness) : 0;
          uint16_t new_square_y = (last_y_pos >= half_thickness) ? (last_y_pos - half_thickness) : 0;
          fillRect(new_square_x, new_square_y, system_line_thickness, system_line_thickness, TFT9341_BLACK);

          // Leave only an outline if possible
          if (system_line_thickness > 2){
              fillRect((new_square_x + 1), (new_square_y + 1), (system_line_thickness - 2), (system_line_thickness - 2), BACKGROUND_COLOR);
          }
        }
        break;
    }
      // Screen brightness control
      case (SYSTEM_STATE_DIMMING): {
          uint16_t current_cnt = TIM2->CNT;
          uint16_t delta = (current_cnt > previous_selector_cnt) ? (current_cnt - previous_selector_cnt) : (previous_selector_cnt - current_cnt);

          // A large jump in a single tick means the counter wrapped
          if (delta > (TIM2->ARR / 2)) {
            current_cnt = (current_cnt < previous_selector_cnt) ? TIM2->ARR : 0;
            TIM2->CNT = current_cnt;
          }
          previous_selector_cnt = current_cnt;

          // Convert TIM2 scale to TIM16 scale with integer division
          TIM16->CCR1 = (current_cnt * TIM16->ARR) / (TIM2->ARR);
        break;
      }

      case (SYSTEM_STATE_THICKNESS_SELECT): {
        uint16_t current_cnt = TIM2->CNT;
        uint16_t delta = (current_cnt > previous_selector_cnt) ? (current_cnt - previous_selector_cnt) : (previous_selector_cnt - current_cnt);

        // Same wrap-clamping as the brightness selector above
        if (delta > (TIM2->ARR / 2)) {
          current_cnt = (current_cnt < previous_selector_cnt) ? TIM2->ARR : 0;
          TIM2->CNT = current_cnt;
        }
        previous_selector_cnt = current_cnt;

        // Scale timer counter to size of uint8 with integer division (multiply first else CNT/ARR == 0)
        system_line_thickness = (current_cnt * MAX_CURSOR_THICKNESS) / (TIM2->ARR);
        
        // Minumum line thickness of 1
        if (system_line_thickness == 0){
          system_line_thickness = 1;
        }

        // Clear the area the larger previous thickness so the new one is visible
        if (system_line_thickness < previous_system_line_thickness){
            uint16_t prev_half_thickness = previous_system_line_thickness / 2;
            uint16_t prev_square_x = (last_x_pos >= prev_half_thickness) ? (last_x_pos - prev_half_thickness) : 0;
            uint16_t prev_square_y = (last_y_pos >= prev_half_thickness) ? (last_y_pos - prev_half_thickness) : 0;
            fillRect(prev_square_x, prev_square_y, previous_system_line_thickness, previous_system_line_thickness, BACKGROUND_COLOR);
        }

        // Preview cursor thickness, centered on the true cursor position
        uint16_t half_thickness = system_line_thickness / 2;
        uint16_t square_x = (last_x_pos >= half_thickness) ? (last_x_pos - half_thickness) : 0;
        uint16_t square_y = (last_y_pos >= half_thickness) ? (last_y_pos - half_thickness) : 0;
        fillRect(square_x, square_y, system_line_thickness, system_line_thickness, TFT9341_BLACK);

        previous_system_line_thickness = system_line_thickness;
        break;
      }

      // Unknown state entered, default to drawing 
      default: {
        state = SYSTEM_STATE_DRAWING;
        break;
      }
    }

    /* USER CODE END WHILE */

    /* USER CODE BEGIN 3 */
  }
  /* USER CODE END 3 */
}

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
/* USER CODE BEGIN 4 */

void HAL_GPIO_EXTI_Callback(uint16_t GPIO_Pin) {
  if (GPIO_Pin == EXTI_PB_1_Pin) {
    pb1_interrupt_fired = true;
  } else if (GPIO_Pin == EXTI_PB_2_Pin) {
    pb2_interrupt_fired = true;
  }
  else if (GPIO_Pin == EXTI_IMU_INT_1_Pin) {
    
    // Read physical INT2 pin state (which mirrors live upside-down status)
    bool is_upside_down = (HAL_GPIO_ReadPin(EXTI_IMU_INT_2_GPIO_Port, EXTI_IMU_INT_2_Pin) == GPIO_PIN_SET);

    if (is_upside_down) {
        confirm_clear_screen_flag = true;
    }
    
    shake_event_flag = true;
  }
}

static void clear_screen(int colour) {
   // Set screen to blank colour without overloading memory
  for (int i = 0; i < 16; i++) {
    fillRect(0, 20 * i, 480, 20, colour);
  }
}

static void fill_cursor_box(uint16_t x, uint16_t y, uint8_t thickness, uint16_t colour){
  
  uint16_t half_thickness = thickness / 2;
  uint16_t square_x = (x >= half_thickness) ? (x - half_thickness) : 0;
  uint16_t square_y = (y >= half_thickness) ? (y - half_thickness) : 0;
  
  fillRect(square_x, square_y, thickness, thickness, colour);
}

/* USER CODE END 4 */
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


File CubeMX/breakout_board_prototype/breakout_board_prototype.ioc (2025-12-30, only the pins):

Mcu.UserName=STM32L433RCTxP
PA0.Signal=S_TIM2_CH1
PA1.Signal=S_TIM2_CH2
PA10.GPIO_Label=TFT_CS
PA10.Signal=GPIO_Output
PA12.GPIO_Label=LCD_MOSI
PA12.Signal=SPI1_MOSI
PA2.GPIO_Label=USART_TX
PA2.Signal=USART2_TX
PA3.GPIO_Label=USART_RX
PA3.Signal=USART2_RX
PA4.GPIO_Label=EXTI_PB_2
PA4.Signal=GPXTI4
PA5.GPIO_Label=LCD_SCK
PA5.Signal=SPI1_SCK
PA6.Signal=QUADSPI_BK1_IO3
PA7.Signal=QUADSPI_BK1_IO2
PA8.Signal=S_TIM1_CH1
PA9.Signal=S_TIM1_CH2
PB0.Signal=QUADSPI_BK1_IO1
PB1.Signal=QUADSPI_BK1_IO0
PB10.Signal=QUADSPI_CLK
PB11.Signal=QUADSPI_BK1_NCS
PB13.GPIO_Label=LD4 [green Led]
PB13.Signal=GPIO_Output
PB2.GPIO_Label=QUADSPI_CS
PB2.Signal=GPIO_Output
PB5.GPIO_Label=EXTI_IMU_INT_1
PB5.Signal=GPXTI5
PB6.GPIO_Label=EXTI_IMU_INT_2
PB6.Signal=GPXTI6
PB8.Signal=S_TIM16_CH1
PC0.GPIO_Label=TFT_DC
PC0.Signal=GPIO_Output
PC1.GPIO_Label=TFT_RST
PC1.Signal=GPIO_Output
PC10.Signal=SPI3_SCK
PC11.Signal=SPI3_MISO
PC12.Signal=SPI3_MOSI
PC13.GPIO_Label=B1 [Blue PushButton]
PC13.Signal=GPXTI13
PC9.GPIO_Label=EXTI_PB_1
PC9.Signal=GPXTI9

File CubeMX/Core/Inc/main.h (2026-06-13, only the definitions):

#define SPI2_CS_Pin GPIO_PIN_11
#define SPI2_CS_GPIO_Port GPIOB
#define EXTI_IMU_INT_1_Pin GPIO_PIN_12
#define EXTI_IMU_INT_1_GPIO_Port GPIOB
#define EXTI_IMU_INT_1_EXTI_IRQn EXTI15_10_IRQn
#define EXTI_IMU_INT_2_Pin GPIO_PIN_13
#define EXTI_IMU_INT_2_GPIO_Port GPIOB
#define EXTI_PB_1_Pin GPIO_PIN_10
#define EXTI_PB_1_GPIO_Port GPIOA
#define EXTI_PB_1_EXTI_IRQn EXTI15_10_IRQn
#define TFT_RST_Pin GPIO_PIN_15
#define TFT_RST_GPIO_Port GPIOA
#define LCD_SCK_Pin GPIO_PIN_3
#define LCD_SCK_GPIO_Port GPIOB
#define LCD_MOSI_Pin GPIO_PIN_5
#define LCD_MOSI_GPIO_Port GPIOB
#define TFT_CS_Pin GPIO_PIN_6
#define TFT_CS_GPIO_Port GPIOB
#define TFT_DC_Pin GPIO_PIN_7
#define TFT_DC_GPIO_Port GPIOB
#define EXTI_PB_2_Pin GPIO_PIN_9
#define EXTI_PB_2_GPIO_Port GPIOB
#define EXTI_PB_2_EXTI_IRQn EXTI9_5_IRQn

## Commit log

2025-11-07 Finish schematic Rev1 and begin layout
    [Etch-a-Sketch.kicad_pcb, Etch-a-Sketch.kicad_sch, SPM10040T-2R2M.step]
2025-11-14 Add footprints and 3D models, initial component layout, hardware improvements
    [EG1224.step, Etch-a-Sketch.kicad_pcb, Etch-a-Sketch.kicad_sch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]
2025-11-17 Initial PCB Layout
    [Coilcraft-LPS3015.STEP, Etch-a-Sketch.kicad_pcb, Etch-a-Sketch.kicad_sch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]
2025-11-18 PCB layout draft and clean files
    [282837-2.step, Etch-a-Sketch.kicad_pcb, Etch-a-Sketch.kicad_sch]
2025-12-09 Final KiCAD updates, and begin driver developpment
    [Etch-a-Sketch.kicad_pcb, Etch-a-Sketch.kicad_sch, PHR-2.step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]
2025-12-10 ICM-42688 Driver Development
2025-12-11 Add driver calibration and style fix
2025-12-11 Add ICM-42688-P Driver
2025-12-16 Add ILI9488 Driver and Basic Functionality
2025-12-18 Configure buttons and drawing on edge fix
    [breakout_board_prototype.ioc, main.c, main.h]
2025-12-22 Initial IMU implementation
2025-12-23 Initial Rev1 Changes, including
    Mounting holes
    Switch to choose backlight reference to replace jumper resistors
    Pull ups/downs for NRST and BOOT0
    Move the debug connector location
    Relabel passive components
    Add jumper resistors to remove power from ICs
    Add diode to prevent reverse powering
    [CJS-1200B_NDC.step, Etch-a-Sketch.kicad_pcb, Etch-a-Sketch.kicad_sch]
2026-01-05 Add Board Revision 1
    [Etch-a-Sketch.kicad_pcb]
2026-04-30 Update Schematic to Rev1
    [Coilcraft-LPS3015.STEP, EG1224.step, Etch-a-Sketch.kicad_pcb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]
2026-05-01 Initial Rev1 PCB Layout
    [2171790001.stp, Etch-a-Sketch.kicad_pcb, Etch-a-Sketch.kicad_sch]
2026-05-08 Change Accelerometer IC
    [Etch-a-Sketch.kicad_pcb, Etch-a-Sketch.kicad_sch, LGA-16_3x3x1mm_STM.step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]
2026-05-16 Send Rev1 Out For Production
    [bom.csv, designators.csv, positions.csv]
2026-06-01 Set Up STM32 Development Files
2026-06-02 Transfer Prototype Code to New Version
2026-06-12 Set Up and Configure Driver Files
2026-06-13 Add Accelerometer config
2026-06-13 Integrate Accelerometer to Project
2026-06-18 Run Rev1 Board!
2026-07-05 Set Internal Pull Up/Down Resistors to Interrupt Pins
2026-07-16 Fix Overshooting Cursor and Cursor Position Storing Across States
    [main.c]
2026-07-17 Remove Selector Wraparound and Fix Thickness Preview
    [main.c]
2026-07-18 Move State Change Out of IRQ
    Slow register reads in the irq was causing a race condition where multiple interrupts in quick succession would preempt and cause incorrect values to be loaded when changing states.
2026-07-20 Fix Previous State Artifact and Update ReadME
    [main.c]
2026-07-20 Fix Eraser Initial State Bug and Enforce Default Cursor Position
    [main.c]

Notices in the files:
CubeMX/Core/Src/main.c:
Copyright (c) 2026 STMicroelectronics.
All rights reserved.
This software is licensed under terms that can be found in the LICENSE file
